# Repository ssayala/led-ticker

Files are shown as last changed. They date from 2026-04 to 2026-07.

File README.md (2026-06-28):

# LED Ticker

Desk sign + ambient ticker built on an ESP32-S3 and a DIYables 4-in-1 MAX7219 LED matrix. Rotates stocks, weather, and a clock; flips to a steady sign or a countdown timer on demand. Wi-Fi only feeds the live data; the sign and timer run fully offline.

<p align="center">
  <picture>
    <source media="(prefers-color-scheme: dark)" srcset="assets/device-sketch-dark.png">
    Line-art illustration of the LED Ticker — a 4-in-1 LED matrix in a bracket, wired to an ESP32-S3 board
  </picture>
</p>

## Features

- **Sign mode** — one-tap status text ("BUSY", "FOCUS", "ON AIR") that overrides the ambient rotation, with an optional auto-clear timer. Or run a **countdown timer** (1–99 min): a live `MM:SS`, an end animation, then back to ambient.
- **Live data** — stock quotes (Finnhub) and multi-location weather (MET Norway).
- **12-hour clock** — steady `H:MM` when shown alone, scrolls `H:MM AM/PM` when mixed in.
- **Display on/off** — blank the matrix and pause fetches without losing the saved ambient mode.
- **Adjustable brightness & scroll speed** — set from the mobile app or CLI, applied live and persisted on the device.
- **Companion mobile app** — multi-device switcher, preset chip grid, and per-category display toggles, on [iOS](https://apps.apple.com/app/id6772027776) and [Android](https://github.com/ssayala/led-ticker-android).
- **Configured entirely over BLE** — no build-time secrets; WiFi, Finnhub key, tickers, locations, mode, timezone, and active sign all set wirelessly and persisted.
- **PIN-gated BLE** — every write requires a 6-digit PIN, generated on first boot and rotated on factory reset.
- **Factory reset** — hold the BOOT button for 10 s to wipe all settings, forget every BLE bond, and reboot into setup mode with a fresh PIN.

## Hardware

A [Freenove ESP32-S3-WROOM (FNK0099)](https://store.freenove.com/products/fnk0099) and a [DIYables 4-in-1 MAX7219 8×8 LED matrix](https://diyables.io/products/dot-matrix-display-fc16-4-in-1-32x4-led). Wiring, porting notes, and pin config are in [Getting started](GETTING_STARTED.md#hardware--wiring). The repo includes a [custom PCB](hardware/pcb/README.md) and a [3D-printable frame](hardware/case/).

## Build & flash

1. Install [PlatformIO](https://platformio.org/).
2. Clone the repo: `git clone https://github.com/ssayala/led-ticker && cd led-ticker`.
3. Build and upload from the repo root: `pio run -d firmware -t upload`, then press the board's reset button.
4. First boot scrolls the BLE name + a 6-digit PIN — note it; you'll need it on every client.

No toolchain? Flash released firmware straight from a browser at **[ledticker.app/flash](https://ledticker.app/flash)**.

Provision from the mobile app or the CLI. (The Wokwi simulator has no BLE — there you provision over a [USB serial console](GETTING_STARTED.md#provisioning-over-usb-serial-opt-in--wokwi) instead.)

## Documentation

- **[Getting started](GETTING_STARTED.md)** — build, flash, first-boot pairing, and `config.h` tuning.
- **[Python client (`led_ticker`)](tools/README.md)** — `pip`-installable library (`from led_ticker import LedTicker`) and the `uv`-based `led.py` CLI, for driving the device or building your own tools.
- **[BLE protocol](BLE_PROTOCOL.md)** — UUIDs, payloads, and semantics for custom clients.
- **[Firmware guide](firmware/FIRMWARE_GUIDE.md)** — firmware internals: dual-core model, display state machine, and how to extend it.
- **[Custom PCB](hardware/pcb/README.md)** — board sources, render, and ordering.
- **[3D-printed frame](hardware/case/)** — printable parts (top/bottom strips or a single bracket) that hold the matrix and PCB together.
- **Companion mobile app** — [iOS](https://apps.apple.com/app/id6772027776) (App Store) and [Android](https://github.com/ssayala/led-ticker-android) (open source).

## License

Open and permissive — free to use, build, modify, share, and sell, including commercially, with attribution.

- **Firmware** — [Apache-2.0](LICENSE).
- **Hardware design files** in [`hardware/`](hardware/) (PCB, mechanical, frame STLs) — [CC BY 4.0](hardware/LICENSE).
- **Python client** in [`tools/`](tools/) (the `led_ticker` package & `led` CLI) — [Apache-2.0](tools/LICENSE).

Attribution is required by these licenses — please keep the credit; see [NOTICE](NOTICE).

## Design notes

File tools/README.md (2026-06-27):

# `led_ticker` — Python library & CLI for the LED Ticker

`led_ticker` speaks the same BLE service as the companion mobile app, so you can drive the
device — or build your own tools — from any machine with Bluetooth. The device
advertises as `LED-Ticker-XXXX`.

## Install

```bash
pip install led-ticker      # or: uv add led-ticker
```

This installs the importable `led_ticker` package and the `led` command.
From a checkout you can also run the CLI with no install via uv:

```bash
uv run tools/led.py <cmd>   # uses ./src directly
```

## Library

```python
from led_ticker import LedTicker, scan

# Scan for available devices (returns DeviceInfo with name, address, rssi):
for d in scan():
    print(d.name, d.address, d.rssi)

# Reuse one connection for several operations:
with LedTicker(pin="482913") as d:
    d.set_tickers(["AAPL", "MSFT"])
    d.set_status("BUSY", minutes=30)
    print(d.get_version())          # -> "0.7.0"
    s = d.get_status()              # -> Status(text="BUSY", seconds=1800)

# Or a one-shot for a single call (opens and closes its own connection):
import led_ticker
led_ticker.set_mode(["stocks", "weather"])
```

`LedTicker(select=None, address=None, name_prefix="LED-Ticker", scan_timeout=4.0, timeout=15.0, pin=None)`.
By default the first `LED-Ticker-*` in range is used; if several are in range it raises
`AmbiguousDeviceError` (whose `.candidates` is a list of `DeviceInfo`). Pass `select=` to
choose a specific unit (see [Selecting a device](#selecting-a-device)), or `address=` to
target a known address directly (skips the scan). Methods raise
`ValidationError`, `AuthError`, `DeviceNotFoundError`, `AmbiguousDeviceError`, or
`ProtocolError` (all subclasses of `LedTickerError`).

`pin=None` does **not** mean "no auth" — it falls back to the same resolution the
CLI uses (`LED_TICKER_PIN` env var, then the `~/.config/led-ticker/pin` cache),
so a saved PIN is picked up automatically. Pass `pin="482913"` to override.

## Selecting a device

With more than one LED-Ticker in range, list them and target one explicitly:

```bash
uv run tools/led.py devices                 # list units: name, address, signal
uv run tools/led.py --device A1B2 status "BUSY" 30   # target by name suffix
```

`--device` matches a unit by its name suffix (the `XXXX` in `LED-Ticker-XXXX`),
its full name, or its Bluetooth address. If you run a command with several units
in range and no `--device`, an interactive terminal prompts you to choose; in a
script (no TTY) it lists the candidates and exits non-zero so you can re-run with
`--device`.

## CLI

```bash
# Sign mode
uv run tools/led.py status "BUSY" 30      # show for 30 min, then auto-clear
uv run tools/led.py status "ON AIR"       # indefinite
uv run tools/led.py status clear

# Timer mode (countdown sign — random animation at zero, then resumes ambient)
uv run tools/led.py timer 10              # 10-minute countdown
uv run tools/led.py timer cancel

# Ambient mode (subset of stocks/weather/clock, 'all', or 'none' for sign-only)
uv run tools/led.py mode stocks weather
uv run tools/led.py mode clock
uv run tools/led.py mode all
uv run tools/led.py mode none

# Power (volatile — power cycle returns to on)
uv run tools/led.py power on
uv run tools/led.py power off

# Display settings (persisted on the device)
uv run tools/led.py display                  # show current brightness + scroll speed
uv run tools/led.py display brightness 8     # brightness 0-15
uv run tools/led.py display speed 50         # scroll ms/step 20-500 (lower = faster)
uv run tools/led.py display 8 50             # both at once

# Timezone (persisted; POSIX TZ string — companion apps have a friendly picker)
uv run tools/led.py timezone                              # show current
uv run tools/led.py timezone "EST5EDT,M3.2.0,M11.1.0"     # US Eastern

# Data
uv run tools/led.py tickers AAPL TSLA NVDA SPY
uv run tools/led.py locations "47.61,-122.33,Seattle"   # lat,lon,label (look up coords online)
uv run tools/led.py apikey your-finnhub-key
uv run tools/led.py wifi My Network Name password

# Inspect
uv run tools/led.py get version           # firmware version on the device
uv run tools/led.py get wifi|apikey|tickers|status|locations|mode|power|display|timezone|version  # read other settings

# Auth
uv run tools/led.py pin 482913            # save the device's PIN locally (~/.config/led-ticker/pin)
uv run tools/led.py pin clear             # forget the saved PIN
uv run tools/led.py --pin 482913 status "BUSY" 30   # use a PIN for one call, without saving it
uv run tools/led.py pin-enforce on        # device: require PIN for writes (default after a fresh flash)
uv run tools/led.py pin-enforce off       # device: stop requiring PIN (escape hatch)

# Maintenance
uv run tools/led.py reload                # force stock refresh
uv run tools/led.py reset                 # wipe NVS, rotate PIN, revert to config.h defaults
```

Save once, every platform: run `led.py pin <6 digits>` a single time and it's replayed on each connection automatically — no per-command `--pin`, on Linux, Windows, and macOS alike. (Companion mobile apps instead use OS-level Bluetooth *bonding* — the phone prompts for the PIN once and the OS remembers it; the CLI never bonds.)

PIN resolution: every command (and the library) looks for the PIN in this order — `--pin XXXXXX` flag → `LED_TICKER_PIN` env var → the saved cache file (`~/.config/led-ticker/pin`). The env var suits CI or anyone who'd rather not write the PIN to disk. If none is found and the device has enforcement on, writes fail with a clear `AuthError`.

Stale-PIN safety: every write probes the device after sending the PIN and exits with a clear error if the PIN was rotated by a factory reset — a write never fails silently because of an out-of-date local PIN.

## License

[Apache-2.0](LICENSE) © 2026 Sunil Sayala — free to use, including commercially, with attribution. (The firmware in the parent repo is also Apache-2.0; the hardware design files are CC BY 4.0 — see the [repo root](https://github.com/ssayala/esp32-led-simple).)

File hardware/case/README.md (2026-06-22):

# 3D-Printed Frame

Two ways to frame the LED Ticker — pick one. Both hold the LED matrix and the [PCB](../pcb/README.md) together so they don't come apart. (Neither encloses the electronics — these are open mounts, not a sealed case.)

| Option | Print | Look |
|---|---|---|
| **Framed** | [`top-strip.stl`](top-strip.stl) + [`bottom-strip.stl`](bottom-strip.stl) | Strips run along the top and bottom edges, framing the display. The strongest hold — the matrix and PCB are gripped along their full length. |
| **Minimal** | [`bracket.stl`](bracket.stl) | A single small bracket joins the matrix and PCB. Less plastic, more bare-electronics look — and still holds plenty well. |

Click any STL above — GitHub renders it in an interactive 3D viewer.

No fasteners in either option; parts friction-fit onto the matrix and PCB. Standard PLA settings work fine.

Designed from scratch in Shapr3D on a Mac — no downloaded model, just calipers, a pile of test prints, and trial-and-error to dial in those friction fits.

## License

Design files licensed [CC BY 4.0](../LICENSE) — free to use, modify, share, and sell with attribution.

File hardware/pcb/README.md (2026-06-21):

# Custom PCB

Carries the Freenove module + a MAX7219 matrix header on a single board. Designed in [EasyEDA](https://easyeda.com/); order via JLCPCB. Sources, mechanical drawing, and render all live in this folder.

<p align="center">
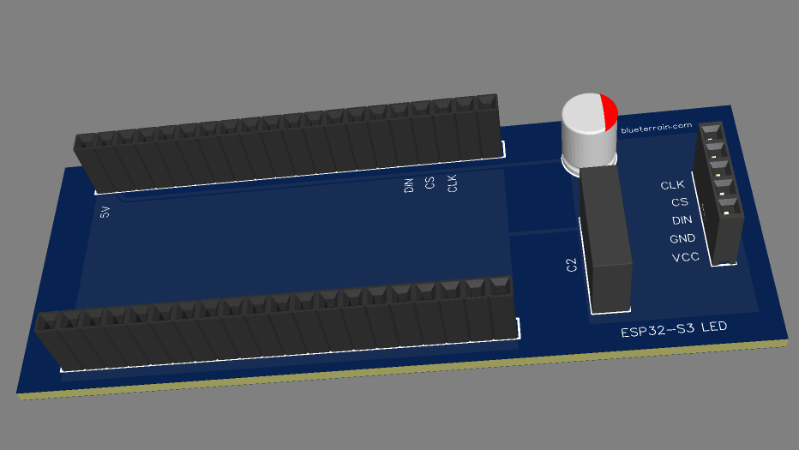
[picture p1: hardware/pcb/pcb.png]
3D render of the custom PCB carrying the Freenove module and the MAX7219 matrix header
  
</p>

## Files

| File | What |
|---|---|
| `EasyEDA_PCB.json` | EasyEDA source project — open this to edit |
| `EasyEDA_PCB.dxf` | Mechanical drawing |
| `pcb.png` | 3D render |

The board is footprint-specific to the **Freenove ESP32-S3-WROOM (FNK0099)** — see [Getting started](../../GETTING_STARTED.md#hardware--wiring) for the matching wiring.

## License

Design files licensed [CC BY 4.0](../LICENSE) — free to use, modify, share, and sell with attribution.

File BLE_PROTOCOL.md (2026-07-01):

# BLE Protocol

The device advertises as `LED-Ticker-XXXX`, where `XXXX` is the low 2 bytes of the chip MAC (so multiple boards on the same bench are distinguishable). All characteristics except `Command` are read/write — reads return current state. `Command` is write-only.

Writes are deferred: the BLE callback copies the payload and a main-loop pass applies it. Writes return immediately even when the change triggers network, display, or NVS work — clients should not assume the effect is observable synchronously.

## Service

`4fafc201-1fb5-459e-8fcc-c5c9c331914b`

## Characteristics

| Characteristic | UUID | Access |
|---|---|---|
| Tickers | `beb5483e-36e1-4688-b7f5-ea07361b26a8` | read/write |
| Mode | `beb5483e-36e1-4688-b7f5-ea07361b26a9` | read/write |
| Command | `beb5483e-36e1-4688-b7f5-ea07361b26ab` | write |
| WiFi | `beb5483e-36e1-4688-b7f5-ea07361b26ac` | read/write (read returns SSID only) |
| API Key | `beb5483e-36e1-4688-b7f5-ea07361b26ad` | read/write |
| Locations | `beb5483e-36e1-4688-b7f5-ea07361b26ae` | read/write |
| Status | `beb5483e-36e1-4688-b7f5-ea07361b26af` | read/write |
| Version | `beb5483e-36e1-4688-b7f5-ea07361b26b0` | read |
| Power | `beb5483e-36e1-4688-b7f5-ea07361b26b1` | read/write |
| Auth | `beb5483e-36e1-4688-b7f5-ea07361b26b2` | write |
| Display | `beb5483e-36e1-4688-b7f5-ea07361b26b3` | read/write |
| Timezone | `beb5483e-36e1-4688-b7f5-ea07361b26b4` | read/write |

UUID `...26aa` was once a "Messages" characteristic and is **not** registered in the current firmware. Reads against it fail at the GATT layer. Don't reuse the UUID.

## Payload formats

### Tickers
Comma-separated symbols. Example: `AAPL,MSFT,GOOGL`. Up to 10 symbols, 15 chars each.

### Mode
A single category (`stocks`, `weather`, `clock`), `all`, `none`, or a comma-separated subset (e.g. `stocks,weather`). Persisted to NVS. The device round-robins through enabled categories. When `clock` is the *only* enabled category the display shows a steady `H:MM`; mixed with others it scrolls `H:MM AM/PM`.

`none` is sign-only mode: no ambient rotation; between signs the display sits on the dim bouncing-pixel idle state. Reads return `"none"`.

Requesting a subset whose prereqs are missing (e.g. stocks without WiFi/API key) diverts the display to **setup mode** — the device scrolls its BLE name until the missing pieces are configured (or the 60s inactivity timer falls into the chosen mode).

The Status characteristic is **orthogonal** to the mode mask: an active sign overrides ambient until cleared or expired. When a sign clears on a device whose prereqs are still unmet, the display drops to **idle** (a single dim bouncing pixel) rather than the setup-name scroll — the user already found the device, so re-scrolling the name would be noise. Mode reads still return the configured mask; idle is an internal display state, not a settable mode.

### Status
Write `text|N` to set, empty payload to clear.

- `N` is unsigned integer *seconds* until auto-clear; `N=0` means indefinite (until cleared).
- Text up to 96 bytes. Short text (≤4 chars) displays steady; longer text scrolls.
- Reads return `text|M` where `M` is seconds remaining (`0` if indefinite), or empty string when no status is active.
- **RAM-only** — a power cycle clears any active sign and resumes ambient.
- Timed signs use the MCU's monotonic `millis()` counter, so they work without WiFi/NTP.
- There is no preset library on the device; preset chips are managed client-side (e.g. a companion app's local list).

### Locations
Pipe-separated `lat,lon,label` triplets — `47.61,-122.33,Seattle|47.67,-122.12,Redmond`. Up to 5 entries, 47 chars each. The **client** geocodes place names to coordinates — companion apps use the phone's location APIs; CLI users look up `lat`/`lon` themselves — so the device never contacts a geocoding service. `lat`/`lon` are decimal degrees; `label` is the text shown on the matrix (≤23 chars, may contain commas — only the first two commas are delimiters). Malformed or out-of-range entries are skipped.

### Command
Write-only.
- `reload` — force an immediate stock + weather fetch.
- `reset` — factory reset: wipe NVS and reboot. The wipe is deferred behind a 9-second single-digit countdown on the matrix (the BOOT-button hold shows the same digits) — **power-cycle the device during the countdown to abort**, since nothing is written until it finishes. Reverts to `config.h` defaults (clears WiFi, API key, any active sign, and the PIN — full reconfiguration needed after; a new PIN is generated and shown in setup mode). The connection drops when the device restarts; the write is ACKed first.
- `pin-enforce on` / `pin-enforce off` — toggle the Auth PIN gate on writes. **On is the default** on a fresh flash.
- `timer <minutes>` — countdown sign (1–99 whole minutes): live `MM:SS`, then a randomly-chosen end animation (fireworks / sonar pulse / sparkle), then ambient resumes. No cooldown — feels immediate, like a sign. Mutually exclusive with the text sign: each cancels the other. RAM-only and fire-and-forget — reads don't report timer state, so clients track the countdown locally.
- `timer cancel` — stop a running countdown and resume ambient immediately.

### WiFi
`SSID|password` — split on the first `|`. Passwords may contain `|`; SSIDs may not. Updates credentials, saves to NVS, reconnects immediately. Reads return the SSID only.

### API Key
Plain string — Finnhub API key. Saved to NVS, triggers an immediate stock fetch.

### Version
Read-only. Returns the firmware version (e.g. `0.1.0`) — the `FW_VERSION` define in `firmware/src/version.h`. Older firmwares won't expose this characteristic; treat its absence as "unknown / pre-0.1.0".

### Power
Write `"on"` or `"off"` (case-insensitive, whitespace-tolerant) to toggle the display. Reads return current state. Unknown payloads are ignored (no GATT error; state unchanged).

- Power is a third orthogonal layer alongside Mode and Status: `"off"` makes the device visually inert (matrix dark, NeoPixel dark, signs suppressed, periodic fetches paused — explicit-refresh writes like ticker updates or `reload` still apply) without touching `enabledMask` or any persisted state. `"on"` resumes the saved ambient mode and triggers an immediate fetch.
- Sign writes while off are accepted and stored but not rendered; on wake, an un-expired sign reappears. Timed signs keep counting down while off.
- **RAM-only — not persisted.** A power cycle returns the device to `"on"`. Older firmwares won't expose it.

### Display
Write `brightness|scroll_ms` — e.g. `4|70`. Brightness is the MAX7219 intensity, 0–15; scroll speed is ms per scroll step, 20–500 (lower = faster). Out-of-range values are clamped, non-numeric or separator-less payloads are ignored. Reads return current values in the same format.

- Persisted to NVS; survives reboot. Factory reset reverts both to the `config.h` defaults (brightness 2, scroll 70).
- Applied immediately — brightness everywhere, scroll speed including an in-flight scroll. Setup mode keeps its own fixed slower scroll until configuration completes.
- Static-sign "breathing" dips up to 4 intensity levels below the configured brightness and recovers, so the setting is the brightest the sign ever gets; the dip clamps at 0 (a brightness-0 sign holds steady).
- Older firmwares won't expose this characteristic.

### Timezone
Write a POSIX TZ string — e.g. `PST8PDT,M3.2.0,M11.1.0` (US Pacific) or `IST-5:30` (India). Up to 63 bytes; must start with a letter. Reads return the current string.

- Persisted to NVS; applied to the display clock immediately. Factory reset reverts to the `config.h` default (US Pacific).
- NYSE market hours are computed in Eastern Time from UTC, independent of this setting.
- Companion apps map a human-readable timezone picker to these strings; the raw format is only needed from the CLI.
- Older firmwares won't expose this characteristic.

### Auth

A BLE connection is "authenticated" (allowed to write to non-Auth characteristics) once either of these happens:

1. **Bonded link:** The device advertises passkey-entry pairing (`bond=true, MITM=true, SC=true`, IO cap `DISPLAY_ONLY`) and asks the central to pair on every fresh connection. The phone shows its native pairing dialog, and the user types the 6-digit PIN from the LED matrix.
2. **PIN write:** The client writes the 6-digit PIN to the Auth characteristic (`…26b2`, write-only). On match, the connection is authenticated for its lifetime. This is the fallback for clients that decline pairing (e.g., Python CLI on Linux).

Reads always work — auth gates writes only.

> [!NOTE]
> Implementation details regarding connection slots (`AuthSlot`), rate-limiting (5 wrong PINs → 5-second silent lockout), concurrent connection limits, and NVS PIN persistence can be found in the [Firmware Guide: Security & Auth](firmware/FIRMWARE_GUIDE.md#7-security-authentication--rate-limiting).

## Cooldown

Writes that trigger upstream network activity — Tickers, Locations, `Command=reload`, `Command=reset` — share a 10-second cooldown to prevent hammering the APIs if a client retries. Other writes (WiFi, API Key, Mode, Status, Power, Display, Timezone, Auth, `Command=pin-enforce`) are not gated.

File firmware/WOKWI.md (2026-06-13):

# Wokwi simulation

A virtual ESP32-S3 + MAX7219 matrix + WS2812 for testing firmware without
hardware. Config lives in [`wokwi.toml`](wokwi.toml) (points at the PlatformIO
build artifacts) and [`diagram.json`](diagram.json) (the wiring, matching the
pins in [`src/config.h`](src/config.h)).

## Run it

1. Build first — the sim runs the compiled binary, not the source:
   ```bash
   pio run -d firmware
   ```
2. Install the **Wokwi for VS Code** extension, open this repo, and run
   **"Wokwi: Start Simulator"** with `firmware/diagram.json` focused. (Or use
   the [Wokwi CLI](https://docs.wokwi.com/wokwi-ci/getting-started).)
3. The serial monitor opens automatically over the board's USB — no TX/RX
   wiring needed. Watch boot logs, the PIN, and `[fetch]` lines there.

## What it can and can't test

| Subsystem | Works? | Notes |
|---|---|---|
| Boot, serial, NVS | ✅ | Emulated flash persists within a session |
| MAX7219 display + scrolling | ✅ | 4 chained modules via the `chain` attr; `"layout": "fc16"` matches the DIYables hardware (`HARDWARE_TYPE` = `FC16_HW`) — omit it and columns render scrambled |
| WS2812 status LED | ✅ | Lights blue during fetches |
| WiFi + HTTP (stocks/weather) | ✅ | Joins `Wokwi-GUEST` with a real internet gateway |
| **BLE / NimBLE control plane** | ❌ | **Not simulated** — no auth, sign mode, or config writes |

Because BLE provisioning is unavailable, a fresh sim boots with empty NVS →
`MODE_SETUP` (shows the device name + PIN), and never fetches.

## Exercising the weather/stock fetch path

The **serial console** (see [`FIRMWARE_GUIDE.md`](FIRMWARE_GUIDE.md) →
"Serial console") is the recommended way to set the API key and other settings
in the sim — BLE isn't available, but serial is. In the Wokwi serial monitor
type `apikey <key>`, `tickers AAPL,MSFT`, etc., then watch the `[fetch]` lines.

For WiFi, `Wokwi-GUEST` uses an **empty password**, which the `wifi` console
command rejects (it requires a non-empty password field). The easiest workaround
is to seed WiFi at boot: in `setup()` after `prefs` init, add a
`#ifdef WOKWI_SIM` block using SSID `Wokwi-GUEST` and an empty password —
**never commit real secrets**. Then the ambient rotation runs against live
Finnhub/MET Norway.

To watch the new 30-minute weather throttle ([`WEATHER_INTERVAL_MS`](src/config.h))
without waiting half an hour, temporarily lower it (e.g. to `60 * 1000`) and
confirm weather fetches less often than the 5-minute stock cadence in the
`[fetch]` serial logs. The throttle's skip path is currently silent — add a
`Serial.printf` there if you want an explicit marker.

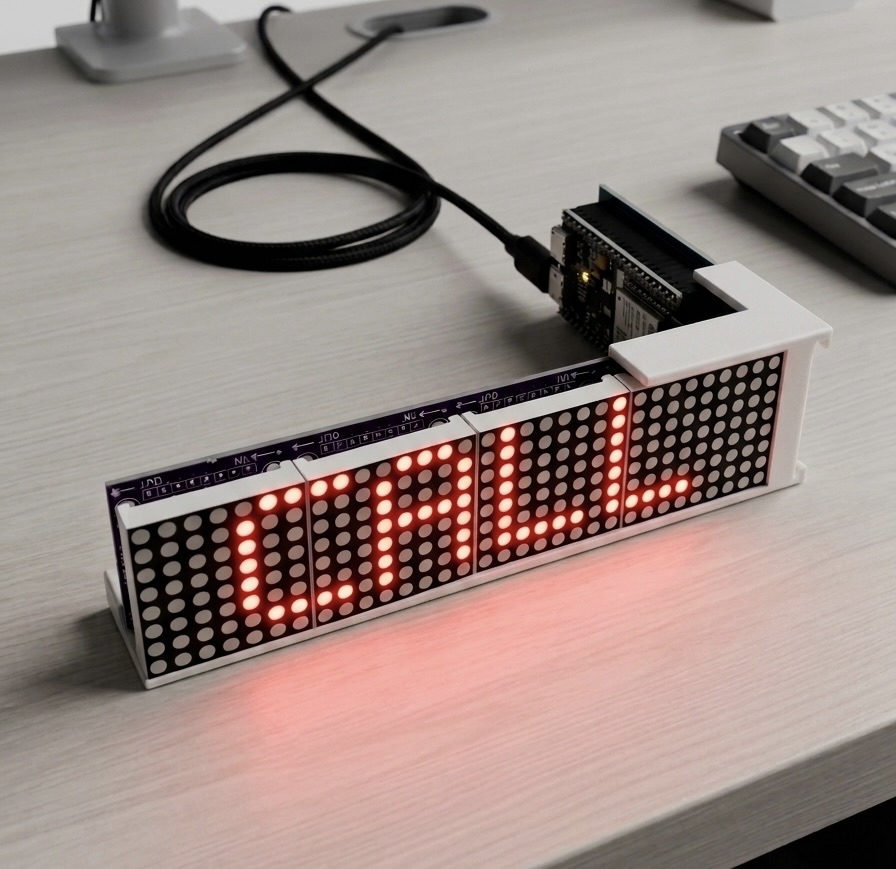
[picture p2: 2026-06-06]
assets/device.jpeg

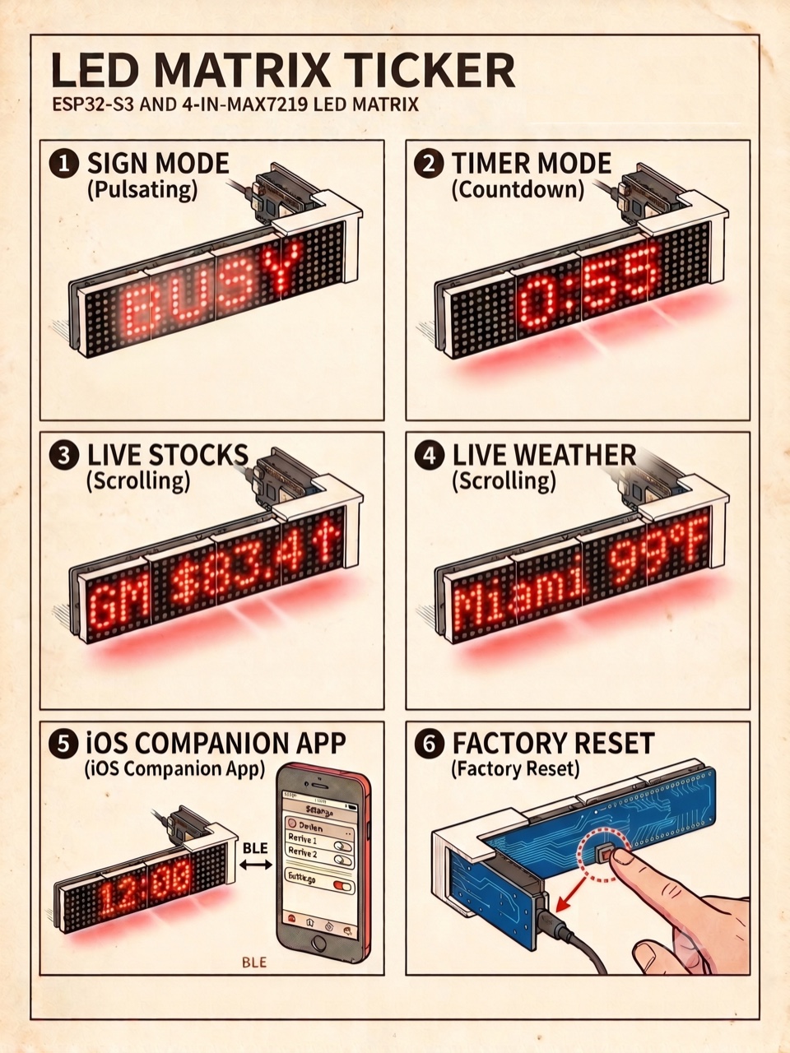
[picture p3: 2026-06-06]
assets/features.jpg

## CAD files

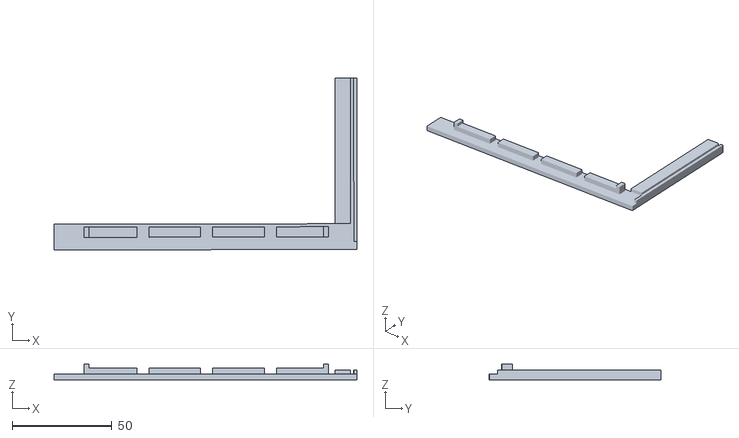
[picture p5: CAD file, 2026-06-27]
hardware/case/bottom-strip.stl
152.0 x 86.1 x 8.00

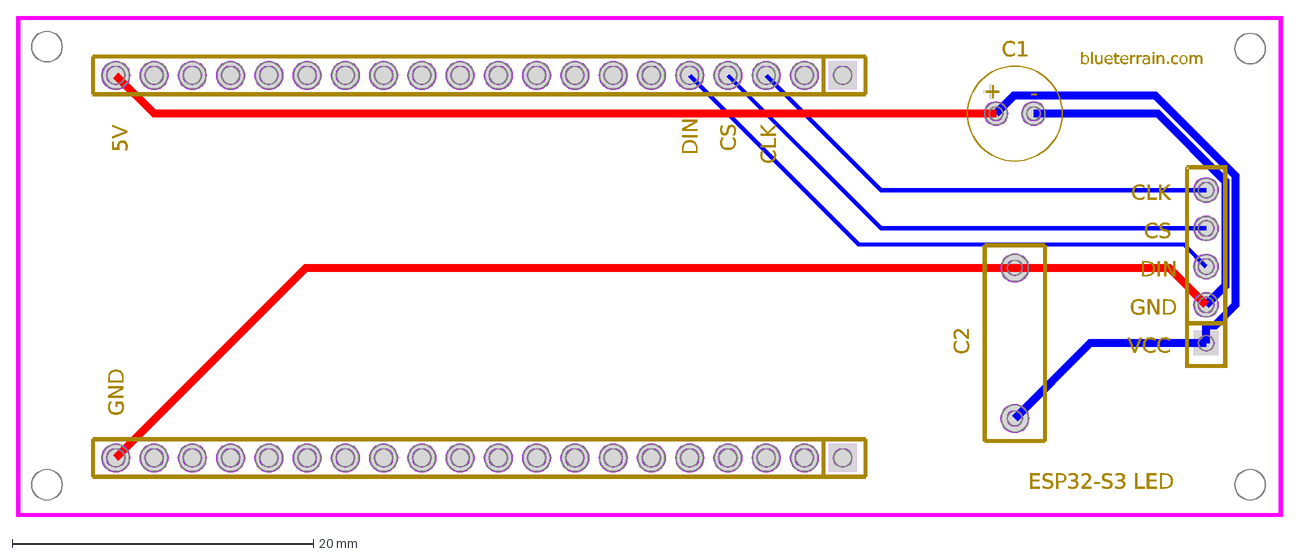
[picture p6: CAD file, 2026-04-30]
hardware/pcb/EasyEDA_PCB.dxf
5V
GND
DIN
CS
CLK
ESP32-S3 LED
blueterrain.com
VCC
C1
+
-
C2

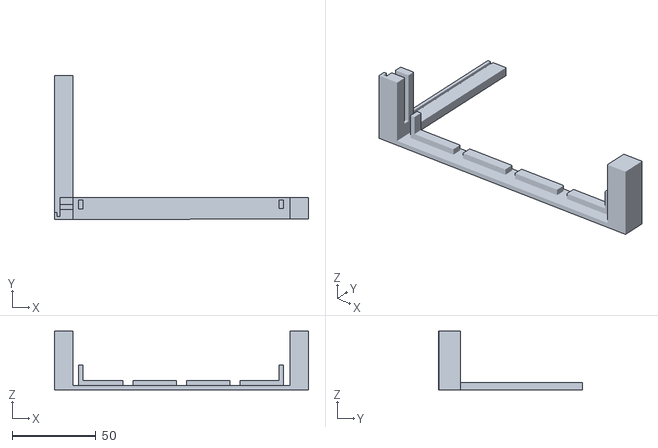
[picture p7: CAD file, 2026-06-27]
hardware/case/top-strip.stl
152.1 x 86.0 x 35.2

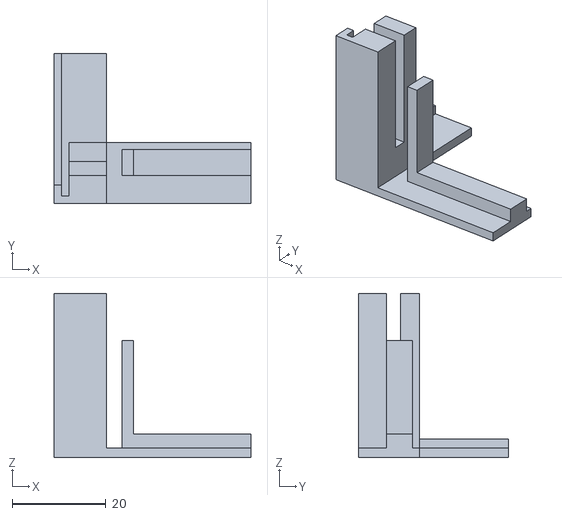
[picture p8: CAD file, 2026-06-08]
hardware/case/bracket.stl
42.0 x 32.0 x 35.0

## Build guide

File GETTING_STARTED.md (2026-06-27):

# Getting started

Build, flash, and configure an LED Ticker. For what it is and what it does, see the [main README](README.md).

## Hardware & wiring

The firmware targets one specific board; the custom PCB is sized for the same module (see [`hardware/pcb/`](hardware/pcb/README.md)).

| Component | Part |
|---|---|
| MCU board | [**Freenove ESP32-S3-WROOM (FNK0099)**](https://store.freenove.com/products/fnk0099) — onboard NeoPixel on GPIO 48, native USB-CDC |
| Display | [DIYables 4-in-1 MAX7219 8x8 LED matrix](https://diyables.io/products/dot-matrix-display-fc16-4-in-1-32x4-led) |

### Wiring (matches the PCB)

| Matrix Pin | ESP32-S3 GPIO |
|---|---|
| VCC | 5V |
| GND | GND |
| DIN | 6 (MOSI) |
| CLK | 4 (SCK) |
| CS | 5 |

Onboard RGB LED (GPIO 48) lights blue during network fetches. The Freenove board's **BOOT button (GPIO 0)** doubles as the factory-reset trigger — hold for 10 s during normal runtime.

**Using a different ESP32-S3 board?** Edit `DIN_PIN` / `CLK_PIN` / `CS_PIN` / `RGB_LED_PIN` in `firmware/src/config.h`. The PCB has no flexibility — it's footprint-specific to the FNK0099.

## Build & flash

1. Install [PlatformIO](https://platformio.org/).
2. Optionally edit defaults in `firmware/src/config.h` — seed tickers/locations (first-boot NVS seed) and the tunables under [Configuration](#configuration) below.
3. Build and upload from the repo root: `pio run -d firmware -t upload`. Press the physical reset button after flashing.
4. On first boot the display scrolls the BLE device name **and a 6-digit PIN** (e.g. `LED-Ticker-AB12  PIN 482 913`). Note the PIN — you'll need it on every client.

> **No toolchain?** Released firmware can be flashed straight from a browser over USB at **[ledticker.app/flash](https://ledticker.app/flash)** — Chrome or Edge on a desktop, no PlatformIO required.

## First-boot pairing

- **Phone app:** open the app, tap the device. The phone pops a system pairing dialog — type the PIN. Bonded. Future reconnects skip the dialog.
- **CLI:** save the PIN once; future calls auto-include it (see the [CLI tool](tools/README.md)):
  ```
  uv run tools/led.py pin 482913
  uv run tools/led.py wifi My Network Name password123
  uv run tools/led.py apikey your-finnhub-key
  ```
  The last arg to `wifi` is always the password — everything before it is the SSID, so spaces work naturally. To avoid saving the PIN to disk, pass `--pin 482913` per command or set `LED_TICKER_PIN=482913` in the environment instead.

If you ever forget the PIN, read it off the serial monitor (`pio device monitor -d firmware`) at boot, or factory-reset to rotate it.

## Provisioning over USB serial (opt-in / Wokwi)

**Most users provision over BLE (above).** The firmware can *also* expose a **serial command console** over USB (115200 baud) that mirrors every BLE setting — but it's a build-time opt-in, **off in the default and released firmware**. Rebuild with `-DCONSOLE_ENABLED=1` to enable it (it's always on in the [Wokwi simulator](firmware/WOKWI.md)). Then open `pio device monitor -d firmware` and type:

```
wifi MyNetwork mypassword
apikey your-finnhub-key
tickers AAPL,MSFT,GOOG
sign HELLO
help
```

`help` lists every verb; `info` prints current state. Full reference — the PIN-bypass rationale and the `wifi` SSID/password split — is in [Firmware guide → Serial console](firmware/FIRMWARE_GUIDE.md).

## Configuration

**User tunables — `firmware/src/config.h`:**

| Define | Default | Description |
|---|---|---|
| `SCROLL_SPEED` | 70 | ms per scroll step (lower = faster) |
| `SETUP_SCROLL_SPEED` | 100 | Slower scroll used only in setup mode so the BLE name + PIN are easy to read. Reverts to `SCROLL_SPEED` once setup completes. |
| `DISPLAY_INTENSITY` | 2 | LED brightness, 0–15. Idle mode (post-sign with no ambient data) dims to 0 regardless of this setting. |
| `SIGN_BREATH_MIN/MAX_INTENSITY`, `STEP_MS` | 1 / 6 / 400 | Subtle brightness pulse on static signs. Tune the three together — changing one in isolation loses the "breath" feel. |
| `TIMEZONE` | `PST8PDT,M3.2.0,M11.1.0` | POSIX TZ string |
| `NTP_SERVER_1` / `NTP_SERVER_2` | `time.google.com` / `time.cloudflare.com` | NTP hosts (anycast, no vendor-zone registration) |
| `FETCH_INTERVAL_MS` | 5 min | Stock + weather refresh interval |

**Hardware pins — `firmware/src/config.h`:** `HARDWARE_TYPE`, `MAX_DEVICES` (4), `DIN_PIN`/`CLK_PIN`/`CS_PIN` (6/4/5), `RGB_LED_PIN` (48), `BUTTON_PIN` (0). Edit these when porting to a different board — see [Hardware & wiring](#hardware--wiring) above.

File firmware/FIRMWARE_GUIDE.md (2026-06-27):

# Firmware Guide

How the ESP32-S3 LED Ticker firmware works, at a high level. The detail lives in the code — `main.cpp` is structured and commented — and the Bluetooth wire format is in [`BLE_PROTOCOL.md`](../BLE_PROTOCOL.md). This is the map, not the territory.

## What it does

Drives a 4-panel LED matrix with two independent layers:

- **Ambient rotation** — cycles through whatever's enabled: stock quotes, weather, and a clock.
- **Override** — a text sign or a countdown timer that takes over the whole panel until it clears, then ambient resumes.

If it hasn't been configured yet (no WiFi or API key), it drops into a **setup** mode instead.

## Two cores

Network calls take seconds; the scrolling has to stay smooth. So the work is split across the ESP32's two cores:

- **Core 0** fetches data over WiFi and runs the Bluetooth stack.
- **Core 1** does everything you see — drives the matrix, runs the display modes, watches the button.

They hand off through shared buffers protected by a mutex. Bluetooth writes never draw or touch the network directly: a callback just stashes the incoming value, and Core 1 picks it up and applies it on its next pass. That keeps the radio and the display from stepping on each other.

```mermaid
graph TD
    subgraph Core0 ["Core 0 — network"]
        A[Fetch task] -->|HTTP| B1[Finnhub stocks]
        A -->|HTTP| B2[MET Norway weather]
        BLE[Bluetooth] -->|stash| Pend[Pending buffers]
    end
    subgraph Core1 ["Core 1 — display"]
        Loop[main loop] -->|applies| Pend
        Loop -->|draws| Disp[LED matrix]
        Loop -->|polls| Btn[Boot button]
    end
    B1 & B2 -->|guarded by mutex| Disp
```

## Display modes

Three top-level modes, plus the override layer on top.

```mermaid
stateDiagram-v2
    [*] --> Setup : not configured
    [*] --> Idle : nothing enabled
    [*] --> Content : configured & enabled
    Setup --> Content : config arrives
    Content --> Idle : everything turned off
    Idle --> Content : a category turned on
```

- **Setup** — not yet usable. Scrolls its Bluetooth name (`LED-Ticker-XXXX`) so you can find it in the app and configure it.
- **Content** — the normal state. Rotates through the enabled categories, skipping any that have no data yet.
- **Idle** — sign-only. Nothing in the rotation, so a single pixel bounces around the panel to show it's alive.

**The override layer** sits above all three. A text sign (short text holds steady; longer text scrolls) or a countdown timer takes over the panel. The timer counts down `MM:SS` and finishes with a brief explosion animation before ambient resumes. The two overrides are mutually exclusive — starting one cancels the other.

When several things want the screen at once, this is the priority order: a factory-reset countdown wins over everything, then power-off (blank), then the timer, then a text sign, then the normal idle/ambient rotation.

## How it's controlled

**Bluetooth is the real control plane** — the companion app talks to it, and that contract (the protocol) is what lets the app evolve without firmware changes. A **USB serial console** mirrors every command; it's there for development and is the only way to drive the device in the Wokwi simulator, where Bluetooth isn't available.

Configuration writes are PIN-gated. The PIN shows on the panel during setup and prints to serial at every boot.

What's saved and what isn't: configuration (WiFi, keys, tickers, locations, brightness, timezone, PIN) persists in flash. Fetched quotes/weather and the active sign are **RAM-only** — a power cycle throws them away and comes back to a clean ambient rotation.

## Where the data comes from

Every few minutes Core 0 refreshes stock quotes (Finnhub) and weather (MET Norway), and the clock syncs from NTP. A couple of things worth knowing:

- Stocks only fetch during US market hours; off-hours it keeps showing the last prices.
- The device doesn't look up locations itself — the app resolves a place name to coordinates and sends those, so the firmware stays simple and keyless for weather.

## Resetting

A factory reset wipes all configuration, forgets paired devices, rotates the PIN, and reboots into setup. Two ways to trigger it — hold the BOOT button for 10 seconds, or send a reset command from the app. Both show a visible countdown you can abort first (release the button, or power-cycle the device).

## If you're editing the firmware

A handful of non-obvious invariants the code depends on — break these and things misbehave in confusing ways:

- **The main loop is cooperative.** Never `delay()` in the middle of it; animations are timed off `millis()` instead, so nothing blocks the scrolling or the radio.
- **Only Core 1 touches the status LED.** Driving it from the fetch task can lock up the LED driver.
- **Don't start the clock (NTP) before WiFi connects** — it wedges the device.
- **Text handed to the display must outlive the call.** The matrix library keeps the pointer you give it, not a copy, so use a static/global buffer, never a local one.

Everything else — exact pin assignments, NVS keys, characteristic UUIDs, the fetch and render functions — is in the source and in [`BLE_PROTOCOL.md`](../BLE_PROTOCOL.md). Read those for specifics; this guide is just the shape of things.

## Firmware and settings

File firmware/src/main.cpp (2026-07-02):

#include <Arduino.h>
#include <ArduinoJson.h>
#include <HTTPClient.h>
#include <MD_MAX72xx.h>
#include <MD_Parola.h>
#include <NimBLEDevice.h>
#include <Preferences.h>
#include <SPI.h>
#include <WiFi.h>
#include <WiFiClientSecure.h>
#include <time.h>

#include "bold_font.h"
#include "config.h"
#include "console.h"
#include "logic.h"
#include "version.h"

// ============================================================================
// File map — read setup() and loop() (bottom, under "Main") first; they are the
// entry points. Everything above them is the units they orchestrate, ordered so
// each definition precedes its first use (C++ requirement, hence entry-points-
// last). Top to bottom:
//
//   Mode bits & hardware constants  — display layers, pins
//   Forward decls                   — the few vars defined out of order
//   NVS: <wifi|apikey|pin|tickers|locations|mask|display|timezone>
//                                   — persisted config; each a save*/load* pair
//   Setup- & active-status state    — RAM-only display state
//   Display / Status LED / Time     — matrix, NeoPixel, NTP + market hours
//   Network fetch                   — Core-0 task hitting Finnhub / MET Norway
//   WiFi connect
//   Display rotation & rendering    — showNext() and the per-mode tick*() drawers
//   BLE                             — characteristics + deferred applyPending*()
//   Main                            — pollResetButton, setup(), console, loop()
//
// Pure, host-tested helpers live in logic.{h,cpp}, not here.
// ============================================================================

// ============================================================================
// Mode bits
// ============================================================================
// An active status sign overrides both modes until expiry/clear.
// 0x02 was once BIT_MESSAGES — tombstoned; legacy NVS masks are stripped
// via `& MASK_ALL` on load. When BIT_CLOCK is the only enabled bit, the
// display switches to a steady non-scrolling clock — see tickStaticClock().

enum {
  MODE_CONTENT,
  MODE_SETUP,
  MODE_IDLE,
};

// The category bits (BIT_STOCKS/WEATHER/CLOCK), MASK_ALL, and the
// MASK_NONE_REQUEST parser sentinel live in logic.h — host-tested alongside
// parseModePayload().

// ============================================================================
// Hardware & display constants
// ============================================================================
// Pins, MAX_DEVICES, and HARDWARE_TYPE are the porting knobs — they live in
// config.h. HARDWARE_TYPE references MD_MAX72XX, which is in scope here
// because this file includes MD_MAX72xx.h above config.h's use site.

// Factory-reset hold timings. GPIO0 (BOOT) is only sampled at reset, so
// runtime polling is safe — but holding it while pressing RESET drops the
// chip into the ROM bootloader instead.
#define RESET_HOLD_MS 10000
#define RESET_HINT_AT_MS 2000
// Remote (BLE/console) reset shows a single-digit countdown before wiping, so
// the user can power-cycle to abort. 9 s ≈ the button's visible window; single
// digit because "10" won't fit the 32 px matrix.
#define RESET_COUNTDOWN_SECS 9

// Scroll buffer cell size. Also bounds STATUS_MAX_LEN.
#define MAX_STRING_LEN 96

// ============================================================================
// Forward decls of vars defined further down (so order-of-definition can
// follow the logical narrative rather than strict topological order).
// ============================================================================

// Defined in the BLE section; consumed earlier by showNextSetup().
extern char bleDeviceName[24];

// ============================================================================
// Preferences (NVS) — single shared instance, used on Core 1 only
// ============================================================================

Preferences prefs;

// Shared persistence for the string lists (tickers, locations): a "count"
// int plus indexed entries ("t0", … / "l0", …). `list` is a flat buffer
// with entry stride `entryLen`. Load seeds from defaults when NVS is empty
// or out of range, and returns the resulting count.

static void saveStringListToNVS(const char* ns, const char* keyPrefix,
                                const char* list, int entryLen, int count) {
  prefs.begin(ns, false);
  prefs.putInt("count", count);
  for (int i = 0; i < count; i++) {
    char key[8];
    snprintf(key, sizeof(key), "%s%d", keyPrefix, i);
    prefs.putString(key, list + i * entryLen);
  }
  prefs.end();
}

static int loadStringListFromNVS(const char* ns, const char* keyPrefix,
                                 char* list, int entryLen, int maxCount,
                                 const char* const* defaults, int defaultCount,
                                 const char* what) {
  prefs.begin(ns, true);
  int count = prefs.getInt("count", 0);
  if (count > 0 && count <= maxCount) {
    for (int i = 0; i < count; i++) {
      char key[8];
      snprintf(key, sizeof(key), "%s%d", keyPrefix, i);
      prefs.getString(key, list + i * entryLen, entryLen);
    }
    prefs.end();
    Serial.printf("Loaded %d %s from NVS\r\n", count, what);
    return count;
  }
  prefs.end();
  int seeded = defaultCount < maxCount ? defaultCount : maxCount;
  for (int i = 0; i < seeded; i++) {
    strncpy(list + i * entryLen, defaults[i], entryLen - 1);
    list[(i + 1) * entryLen - 1] = '\0';
  }
  saveStringListToNVS(ns, keyPrefix, list, entryLen, seeded);
  Serial.printf("Seeded %d %s from defaults\r\n", seeded, what);
  return seeded;
}

// ============================================================================
// NVS: WiFi credentials
// ============================================================================

#define WIFI_SSID_MAX 64
#define WIFI_PASS_MAX 64

char nvsWifiSsid[WIFI_SSID_MAX];
char nvsWifiPass[WIFI_PASS_MAX];

void saveWifiToNVS() {
  prefs.begin("wifi", false);
  prefs.putString("ssid", nvsWifiSsid);
  prefs.putString("pass", nvsWifiPass);
  prefs.end();
}

void loadWifiFromNVS() {
  prefs.begin("wifi", true);
  bool hasSsid = prefs.isKey("ssid");
  if (hasSsid) {
    prefs.getString("ssid", nvsWifiSsid, WIFI_SSID_MAX);
    prefs.getString("pass", nvsWifiPass, WIFI_PASS_MAX);
    Serial.printf("Loaded WiFi credentials from NVS (SSID: %s)\r\n", nvsWifiSsid);
  } else {
    nvsWifiSsid[0] = '\0';
    nvsWifiPass[0] = '\0';
    Serial.println("WiFi not configured — use BLE to set credentials");
  }
  prefs.end();
}

bool wifiConfigured() { return nvsWifiSsid[0] != '\0'; }

// ============================================================================
// NVS: Finnhub API key
// ============================================================================

#define MAX_APIKEY_LEN 64

char nvsApiKey[MAX_APIKEY_LEN];

void saveApiKeyToNVS() {
  prefs.begin("apikey", false);
  prefs.putString("key", nvsApiKey);
  prefs.end();
}

void loadApiKeyFromNVS() {
  prefs.begin("apikey", true);
  bool hasKey = prefs.isKey("key");
  if (hasKey) {
    prefs.getString("key", nvsApiKey, MAX_APIKEY_LEN);
    Serial.println("Loaded API key from NVS");
  } else {
    nvsApiKey[0] = '\0';
    Serial.println("Finnhub API key not configured — use BLE to set it");
  }
  prefs.end();
}

bool apiKeyConfigured() { return nvsApiKey[0] != '\0'; }

// ============================================================================
// NVS: BLE auth PIN
// ============================================================================
// 6-digit PIN gating writes while nvsPinEnforce is on (default). Recovery
// channels: MODE_SETUP scroll and serial at boot. `pin-enforce off` is the
// unauthenticated escape hatch.

#define PIN_LEN 6

char nvsPin[PIN_LEN + 1] = {0};
bool nvsPinEnforce = true;

void savePinToNVS() {
  prefs.begin("pin", false);
  prefs.putString("code", nvsPin);
  prefs.putBool("on", nvsPinEnforce);
  prefs.end();
}

// Persist only the enforce flag — used by `pin-enforce on/off` so toggling
// the gate doesn't rewrite the unchanged 6-byte PIN string back to flash.
void savePinEnforceToNVS() {
  prefs.begin("pin", false);
  prefs.putBool("on", nvsPinEnforce);
  prefs.end();
}

static void generateAndSavePin() {
  uint32_t n = esp_random() % 1000000UL;
  snprintf(nvsPin, sizeof(nvsPin), "%06lu", (unsigned long)n);
  savePinToNVS();
  Serial.printf("Generated new BLE auth PIN: %s\r\n", nvsPin);
}

void loadPinFromNVS() {
  prefs.begin("pin", true);
  bool hasCode = prefs.isKey("code");
  if (hasCode) {
    prefs.getString("code", nvsPin, sizeof(nvsPin));
    // Default to enforcing if the "on" key was never written (e.g. namespace
    // existed from an earlier build that only stored "code").
    nvsPinEnforce = prefs.getBool("on", true);
    Serial.printf("Loaded BLE auth PIN from NVS: %s (enforce=%d)\r\n", nvsPin,
                  nvsPinEnforce);
  } else {
    nvsPin[0] = '\0';
    nvsPinEnforce = true;
  }
  prefs.end();
}

// Separate from loadPinFromNVS so callers can defer until after initBLE():
// esp_random() has no HW entropy until the RF subsystem is up, and a PIN
// generated before that is predictable.
void ensurePinExists() {
  if (nvsPin[0]) return;
  generateAndSavePin();
}

// ============================================================================
// NVS: Stock tickers + in-RAM quote state
// ============================================================================

#define MAX_STOCKS 10
#define MAX_TICKER_LEN 16

char nvsTickers[MAX_STOCKS][MAX_TICKER_LEN];
int nvsTickerCount = 0;

struct StockQuote {
  char symbol[MAX_TICKER_LEN];
  float price;
  float changePct;
};

StockQuote stockQuotes[MAX_STOCKS];
int stockCount = 0;
int currentStock = 0;

void saveTickersToNVS() {
  saveStringListToNVS("tickers", "t", &nvsTickers[0][0], MAX_TICKER_LEN,
                      nvsTickerCount);
}

void loadTickersFromNVS() {
  nvsTickerCount = loadStringListFromNVS(
      "tickers", "t", &nvsTickers[0][0], MAX_TICKER_LEN, MAX_STOCKS,
      stockTickers, stockTickerCount, "tickers");
}

// ============================================================================
// NVS: Weather locations + in-RAM resolution & readings
// ============================================================================

#define MAX_LOCATIONS 5
// MAX_LOCATION_LEN, MAX_LOC_NAME_LEN, the ResolvedLocation struct, and
// parseLocation() live in logic.h/.cpp (host-tested).

char nvsLocations[MAX_LOCATIONS][MAX_LOCATION_LEN];
int nvsLocationCount = 0;

ResolvedLocation resolved[MAX_LOCATIONS];

// Re-derives resolved[] from the stored location strings. Call after locations
// load or change — cheap, no network.
static void reparseLocations() {
  for (int i = 0; i < MAX_LOCATIONS; i++) {
    resolved[i].ok = false;
    if (i < nvsLocationCount) parseLocation(nvsLocations[i], resolved[i]);
  }
}

struct WeatherReading {
  char name[MAX_LOC_NAME_LEN];
  float tempF;
};

WeatherReading weatherReadings[MAX_LOCATIONS];
int weatherCount = 0;
int currentWeather = 0;

void saveLocationsToNVS() {
  saveStringListToNVS("locs", "l", &nvsLocations[0][0], MAX_LOCATION_LEN,
                      nvsLocationCount);
}

void loadLocationsFromNVS() {
  nvsLocationCount = loadStringListFromNVS(
      "locs", "l", &nvsLocations[0][0], MAX_LOCATION_LEN, MAX_LOCATIONS,
      defaultLocations, defaultLocationCount, "locations");
  reparseLocations();
}

// ============================================================================
// NVS: Enabled-category mask
// ============================================================================

uint8_t enabledMask = MASK_ALL;

void saveDisplayMaskToNVS() {
  prefs.begin("display", false);
  prefs.putUChar("mask", enabledMask);
  prefs.end();
}

void loadDisplayMaskFromNVS() {
  prefs.begin("display", true);
  if (prefs.isKey("mask")) {
    // mask=0 is now a valid persisted value ("none" mode — sign-only with
    // idle pixel between signs), so don't fall back to MASK_ALL here.
    enabledMask = prefs.getUChar("mask", MASK_ALL) & MASK_ALL;
  }
  prefs.end();
  Serial.printf("Display mask: 0x%02X\r\n", enabledMask);
}

// ============================================================================
// NVS: Display settings (brightness + scroll speed)
// ============================================================================
// BLE-settable (Display characteristic); clamped at the apply step, so NVS
// only ever holds valid values. Shares the "display" namespace with the mask.

uint8_t displayBrightness = DISPLAY_INTENSITY;
uint16_t scrollSpeedMs = SCROLL_SPEED;

void saveDisplaySettingsToNVS() {
  prefs.begin("display", false);
  prefs.putUChar("bright", displayBrightness);
  prefs.putUShort("scroll", scrollSpeedMs);
  prefs.end();
}

void loadDisplaySettingsFromNVS() {
  prefs.begin("display", true);
  displayBrightness = prefs.getUChar("bright", DISPLAY_INTENSITY);
  scrollSpeedMs = prefs.getUShort("scroll", SCROLL_SPEED);
  prefs.end();
  Serial.printf("Display settings: brightness=%u scroll=%ums\r\n",
                displayBrightness, (unsigned)scrollSpeedMs);
}

// ============================================================================
// NVS: Timezone
// ============================================================================
// POSIX TZ string for the display clock; BLE-settable (Timezone
// characteristic), config.h TIMEZONE is the fresh-flash default. Market
// hours are computed in ET from UTC and don't depend on this.

#define MAX_TZ_LEN 64

char nvsTimezone[MAX_TZ_LEN] = TIMEZONE;

void saveTimezoneToNVS() {
  prefs.begin("time", false);
  prefs.putString("tz", nvsTimezone);
  prefs.end();
}

void loadTimezoneFromNVS() {
  prefs.begin("time", true);
  if (prefs.isKey("tz")) {
    prefs.getString("tz", nvsTimezone, MAX_TZ_LEN);
  }
  prefs.end();
  Serial.printf("Timezone: %s\r\n", nvsTimezone);
}

// ============================================================================
// Setup-mode state
// ============================================================================
// Unmet prereqs drop the display into MODE_SETUP, scrolling the BLE device
// name on a loop. `setupTargetMask` records what to resume into once
// prereqs are met (or after the inactivity timeout).

#define SETUP_TIMEOUT_MS 60000

volatile unsigned long setupLastActivityMs = 0;
uint8_t setupTargetMask = MASK_ALL;

// ============================================================================
// Active-status state (sign mode)
// ============================================================================
// Sign-mode override: a non-empty, unexpired activeStatusText renders in
// place of ambient. statusExpiresAt is a millis() target (not epoch — works
// without NTP); 0 = none, UINT32_MAX = indefinite. Wrap-safe via signed
// delta in checkStatusForRender. RAM-only — power cycle clears the sign.

// ≤4 chars renders static, longer scrolls. Cutoff is 4 not 5 because the panel's
// bold font is wider — 5 wide bold chars overflow 32 cols. See tickActiveStatus()
// and firmware/src/bold_font.h.
#define STATUS_MAX_LEN MAX_STRING_LEN
#define STATUS_STATIC_MAX_CHARS 4

char activeStatusText[STATUS_MAX_LEN] = {0};
uint32_t statusExpiresAt = 0;

void clearStatus() {
  activeStatusText[0] = '\0';
  statusExpiresAt = 0;
}

// ============================================================================
// Display
// ============================================================================

MD_Parola display = MD_Parola(HARDWARE_TYPE, CS_PIN, MAX_DEVICES);

// MD_Parola stores the pointer passed to displayScroll, not a copy.
// Shared across all scrolling content (stocks/weather/clock/status/setup) —
// only one is ever active, and we overwrite only when starting the next scroll.
static char scrollBuf[MAX_STRING_LEN + 1];

// The panel uses two faces: the bold face (bold_font.h) for static content and
// the library's built-in system font for anything that scrolls — bold's 2px
// strokes ghost in motion, and the thin stock font stays crisp even at a fast
// scroll. setFont(nullptr) selects _sysfont (MD_MAX72xx_font.cpp). The scroll
// face is plain mixed-case stock; only the static face is all-caps.
// setFont only takes effect at the next text parse (displayText/displayScroll or
// a displayReset re-parse). Static sites assert the bold face right before
// rendering; every scroll routes through scrollTextAt(), so the scroll face is
// structural rather than remembered per site. const_cast is safe: setFont only
// reads the table (pgm_read_byte).
static void useStaticFont() {
  display.setFont(const_cast<MD_MAX72XX::fontType_t*>(BOLD_FONT));
}
static void useScrollFont() {
  display.setFont(nullptr);  // built-in system font
}

void initDisplay() {
  SPI.begin(CLK_PIN, -1, DIN_PIN, CS_PIN);
  display.begin();
  useStaticFont();  // a face must be set before first render; call sites reassert
  display.setIntensity(displayBrightness);
  display.displayClear();
}

// The one scroll primitive — every scrolling path routes here, so the thin
// scroll face is set in a single place. scrollText() uses the user's configured
// speed; callers that need a different speed (setup) pass it explicitly.
//
// The stock scroll font has real lowercase glyphs, but the panel's identity is
// all-caps (the static face folds a-z onto A-Z), so we fold here too — keeping
// the case uniform between static and scrolling content whatever the input. The
// uppercased copy lands in scrollBuf because MD_Parola keeps the pointer, not a
// copy, so it must outlive the scroll; a self-copy (callers passing scrollBuf)
// is safe since dst and src index in lockstep. Only ASCII a-z folds — the
// degree symbol and arrows (high-bit bytes) pass through untouched.
void scrollTextAt(const char* msg, uint16_t speedMs) {
  size_t i = 0;
  for (; msg[i] && i < sizeof(scrollBuf) - 1; i++) {
    char c = msg[i];
    scrollBuf[i] = (c >= 'a' && c <= 'z') ? c - 'a' + 'A' : c;
  }
  scrollBuf[i] = '\0';
  useScrollFont();
  display.displayScroll(scrollBuf, PA_LEFT, PA_SCROLL_LEFT, speedMs);
}

void scrollText(const char* msg) { scrollTextAt(msg, scrollSpeedMs); }

// ============================================================================
// Status LED (onboard NeoPixel)
// ============================================================================
// Lit blue during network fetches. Driven from loop() via a volatile flag
// set by the fetch task on Core 0 — neopixelWrite from another core hangs.

volatile bool fetching = false;
static bool ledState = false;
// Display power: when true, suppress all rendering and force the NeoPixel
// dark. RAM-only; set via the Power BLE characteristic in the section
// further down. Lives up here so updateStatusLed() (just below) can read it.
static bool displayOff = false;

void updateStatusLed() {
  if (displayOff) {
    if (ledState) {
      neopixelWrite(RGB_LED_PIN, 0, 0, 0);
      ledState = false;
    }
    return;
  }
  if (fetching && !ledState) {
    neopixelWrite(RGB_LED_PIN, 0, 0, 20);
    ledState = true;
  } else if (!fetching && ledState) {
    neopixelWrite(RGB_LED_PIN, 0, 0, 0);
    ledState = false;
  }
}

// ============================================================================
// Time / Market hours
// ============================================================================

bool timeReady = false;

void initTime() {
  // SNTP without WiFi wedges the device on this Arduino core (failed DNS
  // retries accumulate) — the "fresh-boot freeze after tens of minutes" bug.
  if (WiFi.status() != WL_CONNECTED) {
    Serial.println("Skipping NTP init — WiFi not connected");
    return;
  }

  configTzTime(nvsTimezone, NTP_SERVER_1, NTP_SERVER_2);

  Serial.println("Syncing NTP...");
  for (int i = 0; i < 20; i++) {
    struct tm t;
    if (getLocalTime(&t, 100)) {
      timeReady = true;
      Serial.printf("Time: %04d-%02d-%02d %02d:%02d local\r\n", t.tm_year + 1900,
                    t.tm_mon + 1, t.tm_mday, t.tm_hour, t.tm_min);
      return;
    }
    delay(500);
  }
  Serial.println("NTP sync failed, will fetch stocks anyway");
}

// usEasternInDst() (US Eastern DST test for a UTC tm) lives in logic.h/.cpp
// (host-tested).

// NYSE 9:30–16:00 ET, weekdays. Derived from UTC so the user-configurable
// display timezone has no effect here.
bool isMarketOpen() {
  if (!timeReady) return true;  // pre-NTP: assume open so stocks still fetch
  return isMarketOpenAt(time(nullptr));
}
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
void loop() {
  heartbeat(millis());

  pollSerialConsole();  // serial console feeds the same pending* flags
  applyPendingUpdates();

  updateStatusLed();
  if (pollResetButton() || tickResetCountdown()) {
    // A reset countdown (button hold or remote command) owns the display this
    // tick — skip the renderers.
    delay(1);
    return;
  }

  if (currentMode == MODE_SETUP &&
      millis() - setupLastActivityMs > SETUP_TIMEOUT_MS) {
    if (wifiConfigured()) {
      Serial.println(
          "Setup: 60s no activity, falling to content (mask unchanged)");
      enterContent();
    } else {
      // No WiFi → every category is dead; staying on the name scroll beats
      // a "Loading X..." loop. Reschedule the timeout check.
      setupLastActivityMs = millis();
    }
  }

  if (displayOff) {
    // Display is off: skip all render AND fetch work.
    delay(100);
    return;
  }

  renderActiveFrame();

  if (millis() - lastFetch > FETCH_INTERVAL_MS) {
    lastFetch = millis();
    triggerFetch();
  }

  // Yield one tick once this iteration's work is done — lets Core 1 idle (WAITI)
  // instead of busy-spinning at 240 MHz. ~1 kHz loop rate is ample for scroll
  // timing and BLE; cuts idle power/heat. Pacing only — never delay() mid-work.
  delay(1);
}

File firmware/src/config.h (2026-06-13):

#pragma once

// Default stock symbols — used to seed NVS on first boot.
// After that, update them via BLE: uv run tools/led.py tickers AAPL MSFT ...
const char* stockTickers[] = {"AAPL", "GOOG", "MSFT", "AMZN"};
const int stockTickerCount = sizeof(stockTickers) / sizeof(stockTickers[0]);

// Default weather locations — "lat,lon,label" triplets. The client geocodes;
// the device never resolves place names itself. Used to seed NVS on first boot.
// After that, update them via BLE: uv run tools/led.py locations
// "47.61,-122.33,Seattle" ...
const char* defaultLocations[] = {"47.67,-122.12,Redmond",
                                  "47.61,-122.33,Seattle"};
const int defaultLocationCount =
    sizeof(defaultLocations) / sizeof(defaultLocations[0]);

// --- Hardware / pins (edit when porting to a different board) ---
// HARDWARE_TYPE expands at its use site in main.cpp (which includes
// MD_MAX72xx.h), so config.h doesn't need that header itself.
#define HARDWARE_TYPE MD_MAX72XX::FC16_HW
#define MAX_DEVICES 4
#define DIN_PIN 6  // MOSI
#define CLK_PIN 4  // SCK
#define CS_PIN 5
#define RGB_LED_PIN 48  // Freenove onboard WS2812
// Factory-reset button. BOOT button on most ESP32-S3 devkits is GPIO 0.
// GPIO0 is sampled by the bootloader only at hardware-reset time, so polling
// it at runtime is safe. (Hold timings live in main.cpp — they're behavior,
// not a porting knob.)
#define BUTTON_PIN 0

// --- Display behavior ---
// SCROLL_SPEED and DISPLAY_INTENSITY are fresh-flash defaults only — both
// are BLE-settable (Display characteristic) and persisted to NVS.
#define SCROLL_SPEED 70  // ms per scroll step (lower = faster)
// Slower setup-mode scroll so the device name + PIN are readable while
// pairing. Not user-settable.
#define SETUP_SCROLL_SPEED 100
#define DISPLAY_INTENSITY 2  // 0–15

// Static-sign "breathing": intensity dips up to SIGN_BREATH_AMPLITUDE below
// the configured brightness (floor 0), so the user's setting is the
// brightest the sign gets. ~3 s per full breath at 400 ms/step.
#define SIGN_BREATH_AMPLITUDE 4
#define SIGN_BREATH_STEP_MS 400

// --- Timer mode (countdown sign) ---
// Whole-minute countdown rendered as MM:SS, then the end-of-timer animation.
#define TIMER_MAX_MINUTES 99
// End animation (non-blocking, frame-stepped like the idle pixel): a single
// looped "explosion" — a detonation flash, an expanding thick shockwave, and
// diagonal debris rays — fired repeatedly from center until the run ends.
#define ANIM_FRAME_MS 80                         // ms per animation frame
#define ANIM_CENTER_COL ((8 * MAX_DEVICES) / 2)  // 16 on a 4-module matrix
#define ANIM_CENTER_ROW 3
#define EXPLOSION_FRAMES 60         // total frames (~4.8 s at ANIM_FRAME_MS)
#define EXPLOSION_CADENCE 6         // frames between successive detonations
#define EXPLOSION_MAX_R 20          // shockwave radius that clears the matrix
#define EXPLOSION_FLASH_INTENSITY 8 // panel brightness pop on each detonation
// Blank pause after the last explosion frame before ambient resumes — a
// hard cut reads as a glitch.
#define EXPLOSION_END_HOLD_MS 1000

// --- Time / NTP ---
// Default POSIX TZ string for the display clock — BLE-settable (Timezone
// characteristic) and persisted to NVS. Market hours are computed in ET
// from UTC regardless of this setting.
#define TIMEZONE "PST8PDT,M3.2.0,M11.1.0"
// Anycast public NTP — no vendor-zone registration (unlike pool.ntp.org) and
// no per-fleet obligation. Google primary smears leap seconds (no 23:59:60).
#define NTP_SERVER_1 "time.google.com"
#define NTP_SERVER_2 "time.cloudflare.com"

// How often loop() triggers a stocks+weather fetch (5 minutes by default).
#define FETCH_INTERVAL_MS (5 * 60 * 1000)

// Weather changes slowly upstream — throttle it apart from the stock cadence
// so it only hits the API every 30 minutes, not on every fetch tick.
#define WEATHER_INTERVAL_MS (30 * 60 * 1000)

// MET Norway (api.met.no) requires an identifying User-Agent with contact info
// or it returns 403 for new clients. Set this to your project/contact.
#define WEATHER_USER_AGENT "LED-Ticker (https://github.com/ssayala/esp32-led-simple)"

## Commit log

2026-04-30 Initial commit: ESP32-S3 LED matrix ticker
    Scrolling message, stock, and weather ticker for a Freenove ESP32-S3
    driving a DIYables 4-in-1 MAX7219 matrix. Includes BLE control plane,
    Python CLI, SwiftUI iOS companion app, and EasyEDA PCB design files.
    [EasyEDA_PCB.dxf, EasyEDA_PCB.obj]
2026-05-05 Add MODE_SETUP for first-boot and missing-prereq UX
    Transient setup mode shown when WiFi/Finnhub key are missing. Entered on
    boot if WiFi is unconfigured, when stocks/weather are requested without
    their prereqs, or after cmd=reset wipes config. Alternates a contextual
    hint with the BLE device name so the user knows what to connect to.
    Auto-falls to MODE_ALL after 60s of no BLE activity (any write resets the
    timer); exits to the requested mode the moment prereqs are satisfied.
    Also fixes cmd=reset: it cleared NVS but left the in-memory wifi/key
    buffers populated and the WiFi session alive, so the next mode check
    still saw the device as configured.
    Strip stale touch/brightness-knob/buzzer re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
    [main.cpp]
2026-05-17 Replace rotating messages with single-status sign mode
    A list of scrolling messages wasn't useful for a desk display — replace
    it with a one-shot "sign" the user sets on demand ("BUSY", "FOCUS",
    "ON AIR"), with an optional auto-clear timer. Short text renders
    steady (≤5 chars); longer text scrolls.
    Firmware
    - New Status BLE characteristic at ...26af, read/write. Write
    "text|seconds" (0 = indefinite) to set, empty payload to clear.
    Read returns "text|seconds_remaining" or empty when nothing's
    active.
    - Status persists to NVS (text + expiry epoch) so a power blip
    mid-meeting still ends the sign on time. A timed write before NTP
    sync is coerced to indefinite to avoid bad-clock ex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
    [config.h, main.cpp]
2026-05-17 iOS: real bundle ID, gitignore local App Store kit
    Flips the bundle ID off the placeholder com.example.LEDTicker
    (which Apple rejects on upload) to io.github.ssayala.ledticker.
    Also gitignores ios/store/ — that's a personal submission kit
    (metadata templates, privacy policy, etc.) that lives locally and
    shouldn't be in the public repo.
2026-05-17 main.cpp: prune stale and redundant comments
    Fix two factually-wrong comments (parseModePayload still claimed to accept
    "messages"; scrollBuf still mentioned the removed messages scroll), drop
    docstrings that just restated well-named functions, and trim a few verbose
    preambles while keeping the load-bearing WHY. No functional change; build
    size unchanged.
    Also drop hardcoded upload_port/monitor_port from platformio.ini so
    PlatformIO auto-detects the serial device.
    [main.cpp]
2026-05-22 main.cpp: reorganize by section; move user tunables to config.h
    - Reorder top-down: NVS → state → drivers → time → fetch → wifi →
    rendering → BLE → main. Per-BLE-characteristic blocks (UUID +
    pending state + callback + applyPending*) are now co-located instead
    of split across the file. Section banners added. No behavior change.
    - Move SCROLL_SPEED, DISPLAY_INTENSITY, TIMEZONE, NTP_SERVER, and
    FETCH_INTERVAL_MS from main.cpp to config.h; hardware pin/type
    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
2026-05-23 Add MODE_IDLE quiet state + simplify MODE_SETUP display
    - MODE_SETUP now scrolls just the BLE device name on a loop (the
    rotating "Configure WiFi over BLE" / "Set Finnhub key" hints are
    removed — the small audience already knows the BLE-config workflow)
    - New MODE_IDLE: a single dim pixel bounces around the matrix
    Pong-style after a sign clears on a device whose prereqs are still
    unmet. Auto-dims to intensity 0; other modes restore DISPLAY_INTENSITY
    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
2026-05-23 mode=none + sign-only inference + millis()-based sign expiry
    - Add "none" mode token so users can disable all ambient categories
    and run the device in sign-only mode; persists across reboots.
    - Auto-persist mode=none on the first sign write when WiFi is not
    configured — strong signal of sign-only intent. Boot lands in
    MODE_IDLE instead of MODE_SETUP after that.
    - Switch statusExpiresAt from time(NULL) (Unix epoch, NTP-gated) to
    millis(). Timed signs now count down correctly on no-WiFi devices.
    Wrap-safe signed-delta comparison; sentinels 0/UINT32_MAX bumped
    to 1 on collision.
    - Skip fetchTask body when enabledMask == 0; add loop heartbeat and
    fetch start/end logs to help diag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
    [config.h, main.cpp]
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2026-05-25 firmware: clear power-off on reset so device isn't silently dark
    [main.cpp]
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2026-05-25 firmware: fix Power BLE read returning pointer bytes (v0.2.1)
    `pPowerChar->setValue(off ? "off" : "on")` looked correct but matched
    NimBLE-Arduino's `setValue<T>(const T&)` template. The ternary's result
    type is `const char*`, so sizeof(T) was the pointer size (4 bytes on
    ESP32). The library memcpy'd the *pointer address* into the
    characteristic's value buffer instead of the string contents. Reads
    returned 4 bytes of garbage that the iOS parser couldn't recognize as
    on/off, so the Power section silently hid itself.
    Writes were unaffected (they go through onWrite reading the client
    payload), which masked the bug — the toggle worked one direction but
    the state never round-tripped back to cl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
    [main.cpp]
2026-05-25 firmware: reformat main.cpp to K&R style + drop stale comments
    Reformat the whole file to K&R brace style. Also refresh two stale
    comment fragments: the setup-timeout branch referenced a removed
    "Configure WiFi over BLE" hint (setup now scrolls only the BLE device
    name), and parseModePayload's doc didn't mention the "none" /
    MASK_NONE_REQUEST branch.
    No behavior change; firmware builds clean.
    [main.cpp]
2026-05-26 firmware: 24/7 stability — yield loop, stream JSON, heap watermark (v0.2.2)
    - delay(1) at end of loop() so Core 1 enters WFI/light-sleep between ticks
    instead of busy-spinning. Drops idle CPU and chip temperature.
    - Switch fetchStocks / geocode / fetchWeather from http.getString() to
    stream-based deserializeJson(http.getStream()). Eliminates the per-fetch
    String body heap allocation — main remaining source of long-term
    fragmentation.
    - Add ESP.getMinFreeHeap() to the [hb] heartbeat so the worst-case heap
    watermark is observable over uptime.
    [main.cpp]
2026-05-31 firmware: show version on setup screen, bump to v0.3.1
    The MODE_SETUP scroll now reads "LED-Ticker-XXXX v0.3.1 PIN ### ###"
    so the running firmware version is visible on the matrix during setup,
    not just on serial / the Version BLE characteristic. Version sits after
    the device name, ahead of the PIN. Bump FW_VERSION 0.3.0 -> 0.3.1.
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2026-06-04 firmware: wire timer into loop precedence + sign/reset exclusion
    [main.cpp]
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2026-06-04 Added 3D Printable Bracket
    [bracket.stl]
2026-06-05 ios: all-screens UX/HIG cleanup pass
    A consistency + Human Interface Guidelines pass across every screen:
    - Tab bar icons: use the outline cloud.sun for Weather so iOS fills only
    the selected tab — Weather no longer looks permanently active.
    - Spelling: "WiFi" -> "Wi-Fi" everywhere (Apple's house style), in the
    Device tab header and the Display tab hint/status strings.
    - Disconnect is now the standard accent color in both the Device tab and
    the device-picker swipe (was red / orange) — red is reserved for the
    destructive Forget/Reset. The swipe also drops the misleading
    powerplug.fill glyph for xmark.circle.
    - Move the display on/off toggle from the Device tab to the Display ta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
2026-06-05 docs: replace hero photo with the features-guide poster
    Swap the LED photo for assets/features.png — a six-panel guide (sign,
    timer, stocks, weather, iOS app, factory reset) that mirrors the Features
    list and doubles as a visual table of contents. Remove the now-unused
    assets/esp32-led.png.
2026-06-06 docs: add GitHub Pages landing page
    Single-page site under docs/ (served by GitHub Pages from /docs):
    - Dark "control-room" design — real device photo hero, feature cards,
    a "How it works" section, a BOM/build guide, and a footer.
    - LinkedIn-ready: Open Graph + Twitter card meta tags and favicons.
    - App Store badge in the iOS card (placeholder id pending app publish).
    README:
    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
2026-06-06 docs: replace the project-page link with a badge
    Swap the chain-link emoji for a red "Project Page" shields.io badge in
    the LED accent color (#FF2F2F).
2026-06-06 docs: add privacy policy page
    Styled docs/privacy.html (matching the landing page) carrying the existing
    ios/PRIVACY.md content for use as the App Store privacy URL, plus a Privacy
    link in the landing-page footer.
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2026-06-06 docs: show the firmware version on the flash page
    Read the version from firmware/manifest.json and render it as
    "Firmware vX.Y.Z · ESP32-S3" instead of a generic label. The CI
    sync-flasher job now also rewrites the manifest version to match the
    release tag, so the displayed number stays correct on every release.
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2026-06-06 docs: make the landing site fully mobile-ready
    - replace the nav's hide-everything rule below 620px with a real
    hamburger menu (CSS-only toggle, closes on link tap)
    - stack the BOM table into labelled blocks under 540px so it no
    longer cramps or gets clipped on narrow screens
    - add viewport-fit=cover, theme-color, and safe-area-inset padding
    on the sticky nav and footer for notched phones
    - bump mobile tap targets (burger, menu rows, GitHub pill)
2026-06-06 fix: stop the build section scrolling sideways on mobile
    The .bom grid item defaulted to min-width:auto, so the non-wrapping
    git-clone <pre> stretched the column to its full intrinsic width and
    pushed the whole page past the viewport (overflow-x:auto never engaged
    because the parent grew instead). Set min-width:0 on the build-grid
    items so the <pre> scrolls internally.
2026-06-06 docs: tighten hero and copy-edit the landing site
    - drop the four-pill hero badge row (and its now-dead CSS); fold the
    Bluetooth + iOS-app facts into the lede instead
    - rework the lede: split the em-dash sentence, 'can flip ... whenever
    you need it'
    - fix subject-verb agreement ('tries trigger a lockout')
    - standardize 'WiFi' -> 'Wi-Fi' across all pages
    - de-contradict the privacy Wi-Fi clause (name cached; password sent,
    never stored)
    - misc: 'makes it tick', 'ending in', geocoding clause, paired
    em-dashes -> parentheses
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2026-06-06 docs: rewrite 'How it works' and polish hero/meta copy
    - replace the Pairing & PIN and On-device geocoding cards (both echoed
    Features) with a render-precedence and graceful-degradation story;
    sharpen the dual-core, BLE-protocol, and persistence cards
    - 'NVS flash' -> 'flash'; BOOT button replaces the GPIO 0 reference
    - point the iOS card at the real App Store listing, drop the TODO
    - name the chip ('ESP32-S3 microcontroller') in the lede; tidy the
    meta description
2026-06-07 updated bracket
    [bracket.stl]
2026-06-07 release v0.4.5
    Replace the random three end-of-timer animations with a single looped explosion (detonation flash, thick shockwave, debris rays). Tunable via config.h; blast-cap derived from constants and clamped.
    [config.h, main.cpp]
2026-06-08 added case #D Prints (STL)
    [botton-strip.stl, bracket.stl, top-strip.stl]
2026-06-08 Move STL files into assets/case/, fix bottom-strip typo
    Group the three case STLs under assets/case/ and correct the
    botton-strip filename to bottom-strip. Point the website download
    link at the assets/case folder.
    [bottom-strip.stl, bracket.stl, top-strip.stl]
2026-06-09 Updated the 3D Prints
    [bottom-strip.stl, top-strip.stl]
2026-06-10 refactor: reorganize into firmware/, hardware/, notes/ subdirs
    - firmware/: platformio.ini + src/ moved from repo root; pio commands now use -d firmware
    - hardware/: pcb/ and assets/case/ STLs grouped together
    - notes/: gitignored plans/specs moved out of the published docs/ Pages site
    - Updated CI workflow, website links, and all doc paths
    [EasyEDA_PCB.dxf, EasyEDA_PCB.obj, bottom-strip.stl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]
2026-06-10 docs: trim README and CLAUDE.md, link case STLs
    - README: add hardware/case STL links and browser-flasher pointer; drop
    detail duplicated in GETTING_STARTED
    - CLAUDE.md: replace auth/payload/timer detail duplicated in
    BLE_PROTOCOL.md and ARCHITECTURE.md with pointers (~34% smaller)
2026-06-10 docs: tighten BLE_PROTOCOL and ARCHITECTURE, fix pin-enforce default
    - BLE_PROTOCOL: tighter Mode/Status/Power/Auth prose; fix the Command
    section claiming pin-enforce off is the fresh-flash default — firmware
    defaults to on (prefs.getBool("on", true))
    - ARCHITECTURE: merge deferred-apply + cross-core sections, compress
    timer animation and versioning notes
2026-06-11 docs: add case README; update strip STLs
    Document the two mounting options (framed strips vs minimal bracket)
    with links that open GitHub's 3D STL viewer.
    [bottom-strip.stl, top-strip.stl]
2026-06-11 docs: consolidate firmware internals into FIRMWARE_GUIDE, retire ARCHITECTURE
    Fold ARCHITECTURE.md's unique edge-case content (mode-state sentinels,
    sign/timer behavior, boot sequence, data pipeline, reset, versioning) into
    firmware/FIRMWARE_GUIDE.md as the single firmware deep-dive. Remove the four
    overlapping sections so render precedence, cross-core/deferred-apply, the SNTP
    gate, and auth each have one source. Delete ARCHITECTURE.md and repoint README,
    CLAUDE.md, the website, and the BLE_PROTOCOL auth deep-link at the guide.
2026-06-12 weather: throttle Open-Meteo polling to 30 min
    Weather data changes slowly upstream, so polling it on the 5-min stock
    cadence was wasteful. Add WEATHER_INTERVAL_MS (30 min) and self-throttle
    fetchWeatherImpl, mirroring the stocks market-closed skip. Config changes
    (force) and cold boot still fetch immediately; a fully failed fetch leaves
    weatherCount at 0 so the next tick retries.
    release: bump FW_VERSION to 0.5.2
    [config.h, main.cpp]
2026-06-12 docs: fix broken Getting-started link in hardware/pcb/README
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2026-06-13 weather: fetch current conditions from MET Norway
    Open-Meteo's terms bill integrating its API into a commercial product;
    MET Norway (api.met.no) is free, keyless, global, and permits commercial
    use under CC BY 4.0 — removing the last sell-and-forget API tail.
    - fetchWeatherImpl: single GET to locationforecast/2.0/compact, read the
    current instant (timeseries[0]) air_temperature, convert C->F. Filtered
    parse keeps memory small.
    - config.h: WEATHER_USER_AGENT — MET 403s requests without a UA.
    - Docs: swap Open-Meteo -> MET Norway (README, CLAUDE, FIRMWARE_GUIDE).
    [config.h, main.cpp]
2026-06-13 wokwi: track simulator config in the repo
    Add diagram.json, wokwi.toml, and WOKWI.md (previously local-only).
    diagram.json fixes: power rails to real board pins (5V/3V3.x) and the
    FC16 matrix layout attr.
2026-06-13 console: tighten arg invariant, add null test, native warnings
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2026-06-13 console: harden from sim testing + readable serial output
    - sign: send "text|0" (indefinite) so applyPendingStatus() accepts it
    - wifi: "wifi <ssid>" with no password joins an open network (e.g. Wokwi-GUEST)
    - serial console: local echo (printable + backspace) so typing is visible
    - emit CRLF from Serial.printf + a log vprintf hook so raw terminals (Wokwi)
    don't stair-step
    - boot: print esp_reset_reason() to categorize resets
    [main.cpp]
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2026-06-15 release: v0.6.1 — console off on real hardware, remote-reset countdown
2026-06-16 firmware: v0.7.0 — cooler idle, leaner fetches, console dead-code cut
    - loop(): yield delay(1) at end so Core 1 idles (WAITI) instead of
    busy-spinning at 240 MHz — cuts idle power/heat, ~1 kHz loop is ample
    for scroll/BLE. Docs (CLAUDE.md, FIRMWARE_GUIDE.md §10.2) updated to
    carve out the end-of-loop pacing yield.
    - fetch: gate stocks/weather on the enabled-category mask — no API calls
    for categories that aren't displayed. Toggle-on still forces a fetch.
    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
    [bottom-strip.stl, top-strip.stl]
2026-06-16 docs: license hardware design files under CC BY-NC 4.0
    The PCB sources, mechanical drawings, 3D models, and case STLs in
    hardware/ are design works, not software — license them under
    CC BY-NC 4.0 (noncommercial, attribution) rather than stretching the
    firmware's PolyForm license to cover them. Keeps the whole project
    noncommercial while using the right vehicle for design files.
    - add hardware/LICENSE (CC BY-NC 4.0 + attribution header)
    - note the license in hardware/pcb and hardware/case READMEs
    - fix root README: split firmware (PolyForm) vs hardware (CC BY-NC),
    which previously claimed PolyForm covered the hardware files too
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2026-06-18 docs: rewrite firmware guide as a high-level human overview
    Replace the verbose internals deep-dive with a conceptual map of how the
    firmware works: two-core split, display modes + override layer, control
    plane, data sources, reset, and the invariants that bite when editing.
    Specifics now defer to the code and BLE_PROTOCOL.md. Also corrects the
    stale timer end-animation description (one deterministic explosion, not
    three random animations). Point the CLAUDE.md reference at the new shape.
2026-06-18 chore: remove stale plan/spec docs and PCB 3D-model export
    Delete the committed serial-console plan/spec (moved to untracked notes/)
    and the 3.6 MB EasyEDA_PCB.obj/.mtl export — regenerable from the
    EasyEDA_PCB.json source, with pcb.png covering preview. Drop the now-dead
    .obj/.mtl row from the PCB README.
    [EasyEDA_PCB.obj]
2026-06-20 hardware: add diffuser screen cover for the LED matrix
    Optional STEP part that sits over the matrix to hide the bare LEDs and
    soften their glare. Documented in the case README and main README.
    [LED-Screen.step]
2026-06-21 feat(tools): scaffold led_ticker package and error hierarchy
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2026-06-22 refactor(firmware): make main.cpp readable top-down from setup()/loop()
    No behavior change — pure readability:
    - Add a file-map banner at the top listing sections in order and
    pointing readers to setup()/loop() as the entry points.
    - Extract loop()'s inline blocks into named helpers (heartbeat,
    applyPendingUpdates, renderActiveFrame) so loop() reads as a flat
    sequence; the reset/displayOff early-returns stay inline.
    - Extract setup()'s NVS load and boot-mode selection into
    loadConfigFromNVS() and enterBootMode().
    [main.cpp]
2026-06-22 docs(hardware): rename "case" to "frame" — it is an open mount, not an enclosure
    The 3D-printed parts are top/bottom strips (or a single bracket) that
    hold the matrix and PCB together; nothing encloses the electronics.
    "Case" overclaimed. Folder path hardware/case/ left as-is to avoid
    breaking links.
2026-06-22 hardware: remove unused LED-Screen.step screen cover
    Drop the optional face-cover STEP file and its references in the README
    and frame guide — not used.
    [LED-Screen.step]
2026-06-26 fix(firmware): repaint active sign after category change
    applyPendingMode() resets the display buffer via enter*() but did not
    invalidate the sign render cache (statusShown), so an active timed sign
    was skipped on the next tick and the display went blank. Drop the cache
    so the sign repaints, matching every other display-reset path.
    release: firmware v0.7.2
    [main.cpp]
2026-06-27 Added adjusted STL Files
    [bottom-strip.stl, top-strip.stl]
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2026-07-02 feat(firmware): thin scroll font, keep static bold, bump to 0.9.3
    Scrolling content ghosted: the bold face's 2px strokes linger ~2 frames
    per retinal cell at 1 col/frame, smearing at fast scroll speeds. Render
    all scrolling content (ambient rotation, long signs, setup) in the
    built-in system font instead; static content (short signs, steady clock,
    timer, reset digits) keeps the bold face, where there's no motion to
    ghost.
    To preserve the panel's all-caps identity across both faces, fold ASCII
    a-z to A-Z on the scroll path (the stock font has real lowercase glyphs;
    the degree symbol and arrows pass through untouched).
    Consolidate every scroll path through a single scrollTextAt(msg, speed)
    p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
    [main.cpp]
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
